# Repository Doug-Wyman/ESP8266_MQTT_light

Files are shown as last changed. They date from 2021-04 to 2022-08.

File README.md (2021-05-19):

# ESP8266_MQTT_light
Micropython code for controlling an RGB and White light 
using an ESP8266 controller board of my design

This code is poorly written alpha code to control a 12 VDC RGB light 
and a 12 VDC white light using MQTT. It works but needs improvement. 

The switches control on/off with a short press and dimming/brightening 
when they are held down.  

OSH Park is making my controller board (click on image)
<a href="https://oshpark.com/shared_projects/GQtievsf">
OSH Park</a>.  
The design is an Eagle cad design but there is a caveat!!
The switches come with 4 pins two pair of bussed through hole.
However even though the foot print is identical there are 
two varieties.  With the opposite connections. The board traces
will show the bussed pairs.

Being very new to ESP8266 and micropython it seems as though the code 
is near the memory limit of the ESP8266.
So I have eliminated all comments and extras.  
I welcome suggestions and corrections.  

The entire project is for a Home-Assistant installation.
I have 4 sets of lights working. I was experiencing disconnect fails 
when either the HASS server or the Mosquitto server was rebooted 
so I wrote the code so it reboots the ESP8266
GPIO-16 controlls the blue LED on the ESP8266 board I am using so the
code turns it on during boot then off once booted.  So it acts as an
indicator of when the board is in boot mode.

I have included a sample configuration for Home Assistant control of the module.
The script will return the version which will fill the sensor value.

The Code:
boot.py starts by loading the webrepl which probably won't be needed in production.
The parameters file is loaded and contains data for the WiFi connection, 
the MQTT instance, the pin data for the ESP8266 and such.

The status file is essentially the JSON state last saved so the light on boot 
is set to the last known state. 

Boot then calls main.  Main starts by opening the MQTT connection.
If there is an error in connecting, the program flashes the LED on the ESP8266 three times 
in a one second on one second off and exits.

On a good MQTT connection , the routine sets a callback address for received messages 
and returns the connected client.

The code enters the main loop. It does an MQTT message check first then 
the state of the switches is checked.  A short press/release will toggle the on/off state.
After the button is held down for a period longer than the counter is set for,
the light goes into a brighten/dim cycle.

After any change in state, the state file is updated and an MQTT status message is sent.
The last thing in the loop is a check to see when we sent the last status and
to send an update when timed out.

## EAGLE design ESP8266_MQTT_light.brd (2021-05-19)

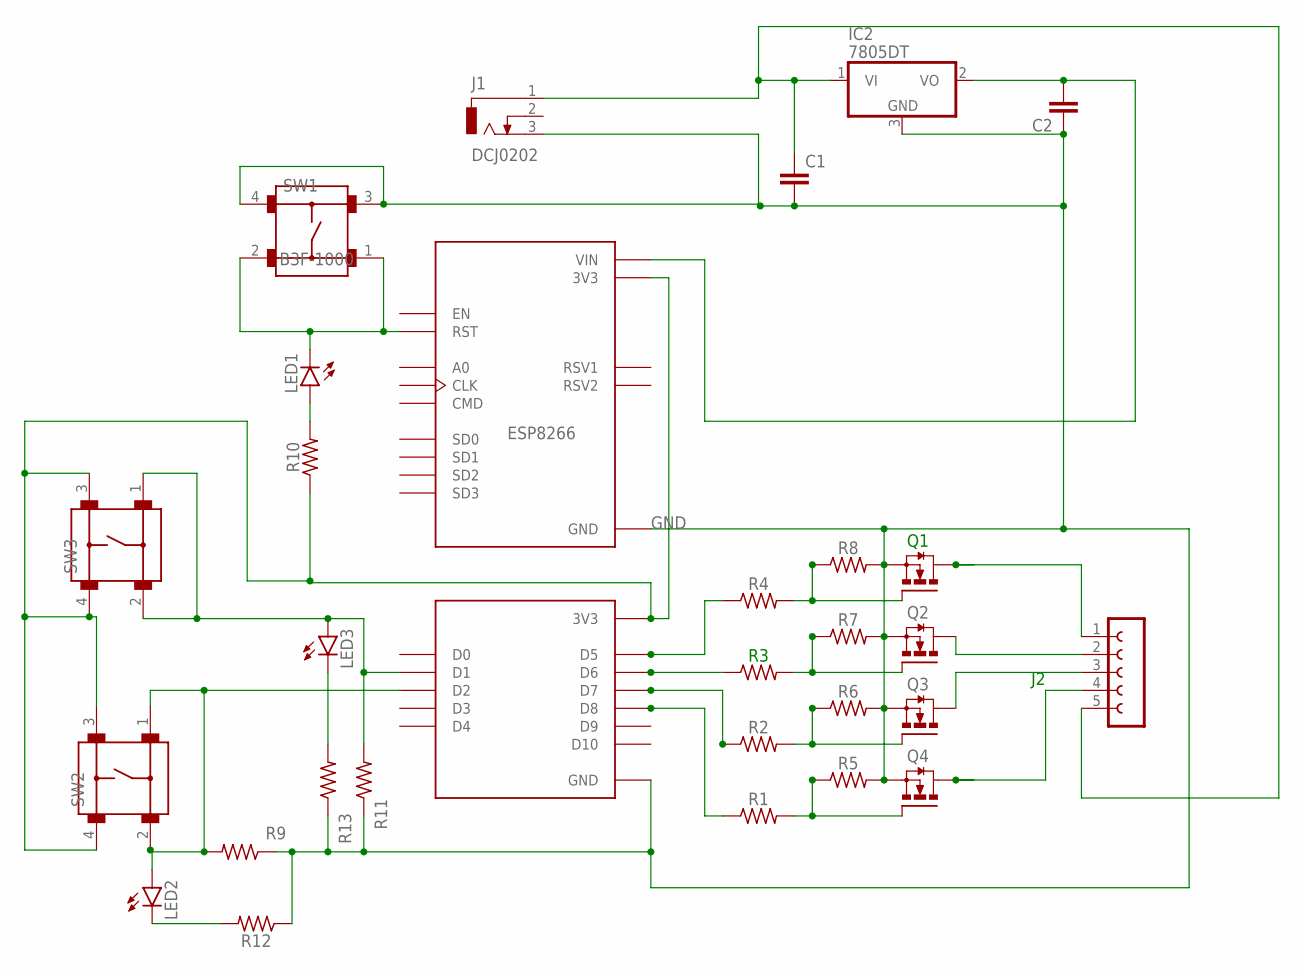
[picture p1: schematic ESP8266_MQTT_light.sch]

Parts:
C1, C2: CC1005; C1005
ESP8266: 113990105; SEEED_113990105
IC2: 7805DT; TO252
J1: DCJ0202
J2: RGBW1; FE05W
LED1, LED2, LED3: LEDCHIPLED_1206; CHIPLED_1206
Q1, Q2, Q3, Q4: IRF3704S; D2PACK
R1, R2, R3, R4: 1k; R1206
R5, R6, R7, R8, R9, R11: 10k; R1206
R10, R12, R13: 33; R1206
SW1, SW2, SW3: B3F-1000

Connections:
3.3VDC: ESP8266.J1_11 (3V3), ESP8266.J2_6 (3V3), ESP8266.J2_15 (3V3), R10.1, SW2.3, SW2.4, SW3.3, SW3.4
5VDC: C2.2, ESP8266.J1_15 (VIN), IC2.2 (VO)
12VDC: C1.1, IC2.1 (VI), J1.1, J2.5
B-IN: Q2.1 (G), R3.2, R7.1
B-MAIN: ESP8266.J2_9 (D6), R3.1
B-OUT: J2.2, Q2.2 (D)
G-IN: Q3.1 (G), R2.2, R6.1
G-MAIN: ESP8266.J2_10 (D7), R2.1
G-OUT: J2.3, Q3.2 (D)
GND: C1.2, C2.1, ESP8266.J1_10 (GND), ESP8266.J1_14 (GND), ESP8266.J2_7 (GND), ESP8266.J2_14 (GND), IC2.3 (GND), J1.3, Q1.3 (S), Q2.3 (S), Q3.3 (S), Q4.3 (S), R5.2, R6.2, R7.2, R8.2, R9.1, R11.1, R12.1, R13.1, SW1.3, SW1.4
unnamed: LED1.A, R10.2
unnamed: LED2.C, R12.2
unnamed: LED3.C, R13.2
unnamed: ESP8266.J2_3 (D2), LED2.A, R9.2, SW2.1, SW2.2
R-IN: Q4.1 (G), R1.2, R5.1
R-MAIN: ESP8266.J2_11 (D8), R1.1
R-OUT: J2.4, Q4.2 (D)
RESET: ESP8266.J1_13 (RST), LED1.C, SW1.1, SW1.2
W-CTL: ESP8266.J2_2 (D1), LED3.A, R11.2, SW3.1, SW3.2
W-IN: Q1.1 (G), R4.2, R8.1
W-MAIN: ESP8266.J2_8 (D5), R4.1
W-OUT: J2.1, Q1.2 (D)

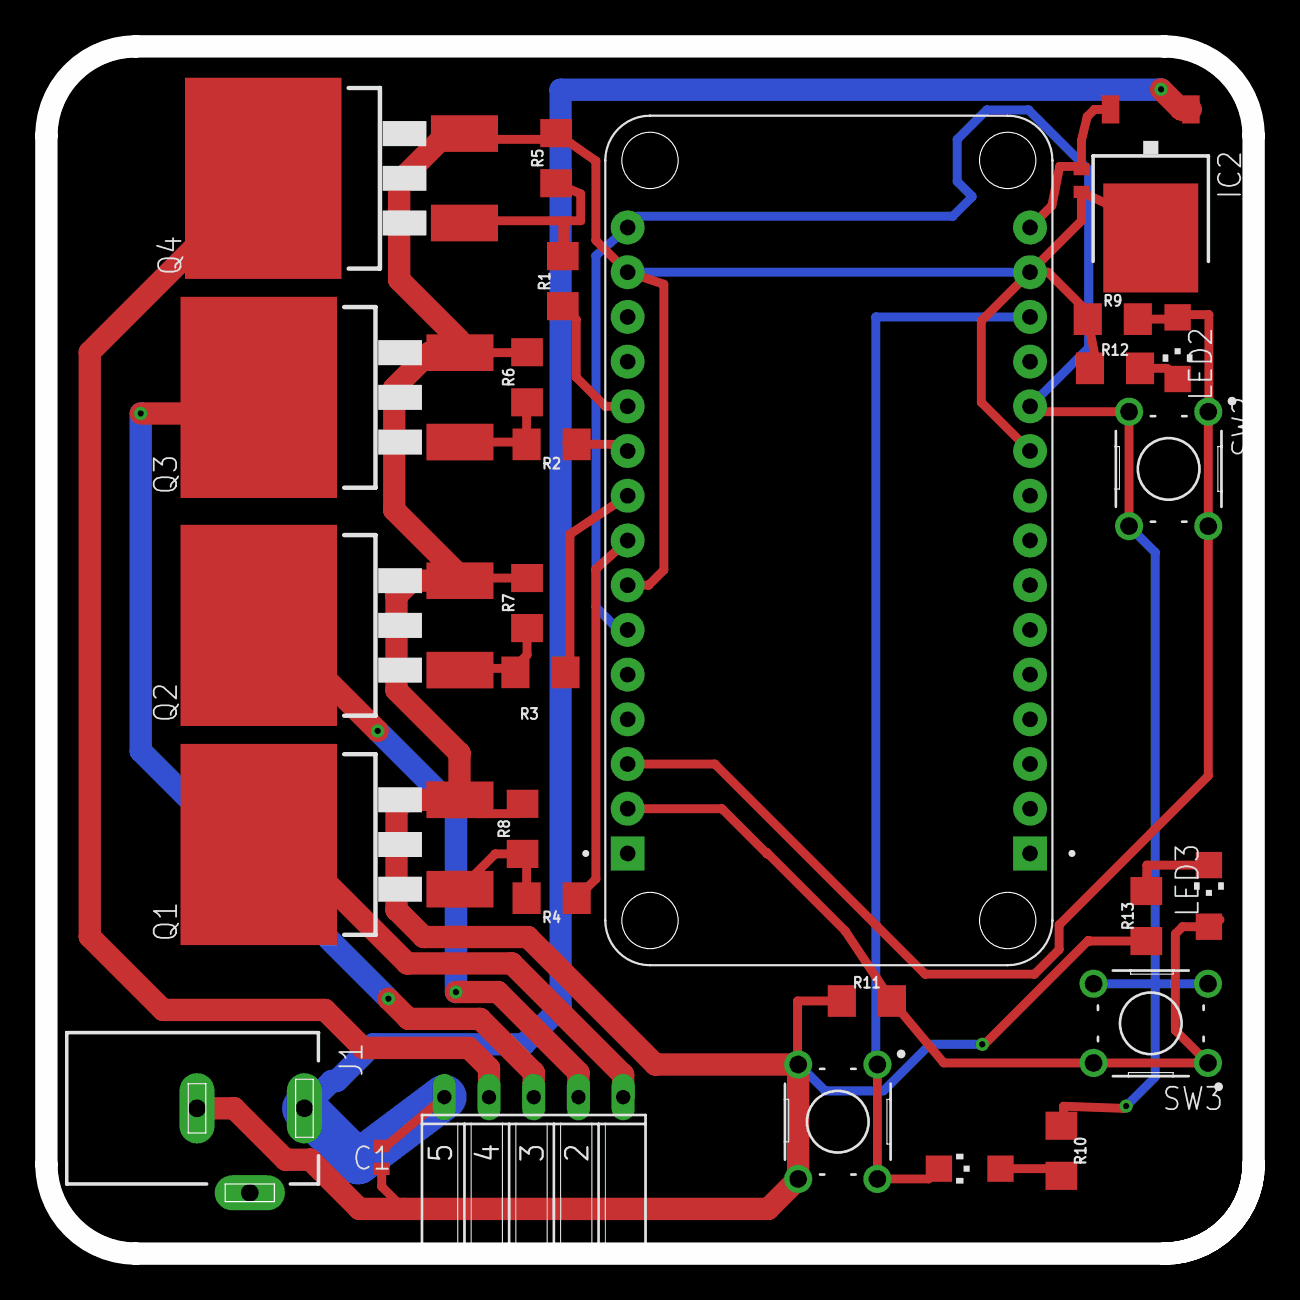
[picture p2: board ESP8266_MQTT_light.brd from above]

Board: 2 copper layers, 68.6 x 68.6 mm, 29 parts (0 on the bottom side), 22 nets.

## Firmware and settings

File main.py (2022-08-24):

#import machine
from machine import RTC
import time
from time import sleep
import os
import ujson
from umqtt.simple import MQTTClient
################# main for light ########################
def savestate():
  global status, BUSY
  statusfile = open('status', 'w')
  myjson = ujson.dumps(status)
  statusfile.write(str(myjson))
  statusfile.close()
  print("saved" + str(status))
  
def received(topic, inmsg):
  global status, BUSY, ROOT_TOPIC
  if not BUSY and topic != ROOT_TOPIC + b'white/state' and topic != ROOT_TOPIC + b'rgb/state':
    BUSY = True
    #print(topic, inmsg)
    msg = inmsg.decode('utf-8')
    print(msg)
    ##############WHITE######################
    if topic == ROOT_TOPIC + b'white/switch':
      print('ESP received switch')
      
      newset = ujson.loads(msg)
      print(newset)
      status['white']['state'] = newset.get('state', status['white']['state'])
      status['white']['brightness'] = newset.get('brightness', status['white']['brightness'])
      if status['white']['state'] == 'ON':
        WHITE_PIN.duty(status['white']['brightness'])
      else:
        WHITE_PIN.duty(0)
      client.publish(ROOT_TOPIC + b'white/state', str(ujson.dumps(status['white'])))
      savestate()
    ########################rgb#######################
    if topic == ROOT_TOPIC + b'version?':
      print('ESP version request')
      client.publish(ROOT_TOPIC + b'version', 'Version 2021.091')
    if topic == ROOT_TOPIC + b'rgb/switch':
      print('RGB received switch')
      newset = ujson.loads(msg)
      print(newset)
      status['rgb']['state'] = newset.get('state', status['rgb']['state'])
      status['rgb']['brightness'] = newset.get('brightness', status['rgb']['brightness'])
      status['rgb']['color'] = newset.get('color', status['rgb']['color'])
      if status['rgb']['state'] == 'ON':
        BRIGHTMULTIPLIER = float(status['rgb']['brightness'] / 1024)
        red = int(float(status['rgb']['color']['r'] /255) *1024)
        red = int(red * BRIGHTMULTIPLIER )
        green = int(float(status['rgb']['color']['g'] /255) * 1024)
        green = int(green * BRIGHTMULTIPLIER)
        blue = int(float(status['rgb']['color']['b'] /255) * 1025)
        blue = int(blue *  BRIGHTMULTIPLIER)
        print("red is:" + str(red))
        print("green is:" + str(green))
        print("blue is:" + str(blue))
        RED_PIN.duty(int(red))
        GREEN_PIN.duty(int(green))
        BLUE_PIN.duty(int(blue))
      else:
        RED_PIN.duty(0)
        GREEN_PIN.duty(0)
        BLUE_PIN.duty(0)
      client.publish(ROOT_TOPIC + b'rgb/state', str(ujson.dumps(status['rgb'])))
      savestate()
    BUSY = False
  else:
    print('.', end='')

def connect_and_subscribe():
  global CLIENT_ID, BROKER_ADDRESS, ROOT_TOPIC, client, SWITCH_PIN
  try:
    SWITCH_PIN.value(0)
    client = MQTTClient(CLIENT_ID, BROKER_ADDRESS)
    client.set_callback(received)
    client.connect()
    time.sleep(2)
    print("connecting")
    client.subscribe(ROOT_TOPIC + b'#')
    print('Connected to %s MQTT broker, subscribed to %s topic' % (BROKER_ADDRESS, ROOT_TOPIC))
    SWITCH_PIN.value(1)
    client.publish(ROOT_TOPIC + b'version', 'Version 2021.091')
    return client
  except:
    SWITCH_PIN.value(1)
    time.sleep(1)
    SWITCH_PIN.value(0)
    time.sleep(1)
    SWITCH_PIN.value(1)
    time.sleep(1)
    SWITCH_PIN.value(0)
    time.sleep(1)
    SWITCH_PIN.value(1)
    time.sleep(1)
    SWITCH_PIN.value(0)
    return None

################# main for light ########################
print("Loading.............")
client = connect_and_subscribe()
sleep(2)
last_message = 0
message_interval = 30
time_interval = 3600
#wdt.feed()
lastin = 1
counting = False
sw1count = 0
savtime = ''
#wdt.feed()
#print(dir(client.ping))
short_time = 5
down_time = 50

ctrlw_down = 0
ctrlw_raise = False
ctrlw_short = 0
ctrlw_level = 0

ctrlm_down = 0
ctrlm_raise = False
ctrlm_short = 0
ctrlm_level = 0
while 1:
  try:
    try:
        client.check_msg()
    except:
        print("error checking")
        client = connect_and_subscribe()
#######################start white contro
    if CTRL_WHITE.value() == 0:
      #print(".", end='')
      if ctrlw_short > 0:
        print("XX", end='')
        ctrlw_short += 1
        if ctrlw_short > short_time:
          ctrlw_short = 0
          print(str(status['white']['state']) == 'OFF')
          #######Toggle state##########
          if str(status['white']['state']) == 'OFF':
              WHITE_PIN.duty(status['white']['brightness'])
              status['white']['state'] = 'ON'
          else:
              WHITE_PIN.duty(0)
              status['white']['state'] = 'OFF'            
          client.publish(ROOT_TOPIC + b'white/state', str(ujson.dumps(status['white'])))
          savestate()
    if CTRL_WHITE.value() == 1:
      print("after short2" + str(ctrlw_short))
      print("||||||", end='')
      ctrlw_down = 0
      ctrlw_level = int(status['white']['brightness'])
      if ctrlw_short > 1:
        ctrlw_raise = True
      else:
        ctrlw_dimming = True
      print(ctrlw_level)
      while CTRL_WHITE.value() == 1:
        ctrlw_down += 1
        if ctrlw_down > down_time:
          WHITE_PIN.duty(ctrlw_level)
          if ctrlw_level < 1:
            ctrlw_raise = True
          if ctrlw_raise == True:
            ctrlw_level = int(ctrlw_level) + 1
            if int(ctrlw_level) > 1024:
              print("Stop Bright")
              #ctrlw_dimming = True
              ctrlw_raise = False
              ctrlw_short = 0
            else:
              ctrlw_raise = True
          else:
            ctrlw_level -= 1
            if ctrlw_level < 1:
              ctrlw_raise = True
        sleep(.01)
      if ctrlw_down > down_time:
        ctrlw_short = 0
        ctrlw_down = 0
      else:
        ctrlw_short = 1
      ctrlw_raise = False
      ctrlw_dimming = False
      status['white']['brightness'] = ctrlw_level
      if ctrlw_down == 0: 
        client.publish(ROOT_TOPIC + b'white/state', str(ujson.dumps(status['white'])))
        savestate()
      ctrlw_raise = False
      ctrlw_dimming = False
      print("after short1" + str(ctrlw_short))
#######################logic#################################
    if CTRL_MOOD.value() == 0:
      #print(".", end='')
      if ctrlm_short > 0:
        print("XX", end='')
        ctrlm_short += 1
        if ctrlm_short > short_time:
          ctrlm_short = 0
          print(str(status['rgb']['state']) == 'OFF')
          #######Toggle state##########
          if str(status['rgb']['state']) == 'OFF':
            #WHITE_PIN.duty(status['rgb']['brightness'])
            status['rgb']['state'] = 'ON'
            BRIGHTMULTIPLIER = float(status['rgb']['brightness'] / 1024)
            red = int(float(status['rgb']['color']['r'] /255) *1024)
            red = int(red * BRIGHTMULTIPLIER )
            green = int(float(status['rgb']['color']['g'] /255) * 1024)
            green = int(green * BRIGHTMULTIPLIER)
            blue = int(float(status['rgb']['color']['b'] /255) * 1025)
            blue = int(blue *  BRIGHTMULTIPLIER)
            print("red is:" + str(red))
            print("green is:" + str(green))
            print("blue is:" + str(blue))
            RED_PIN.duty(int(red))
            GREEN_PIN.duty(int(green))
            BLUE_PIN.duty(int(blue))
          else:
            RED_PIN.duty(0)
            GREEN_PIN.duty(0)
            BLUE_PIN.duty(0)
            status['rgb']['state'] = 'OFF'
          client.publish(ROOT_TOPIC + b'rgb/state', str(ujson.dumps(status['rgb'])))
          savestate()
    if CTRL_MOOD.value() == 1:
      print("||||||", end='')
      ctrlm_down = 0
      ctrlm_level = int(status['rgb']['brightness'])
      if ctrlm_short < 1:
        ctrlm_raise = True
      else:
        ctrlm_raise = False
      while CTRL_MOOD.value() == 1:
        ctrlm_down += 1
        if ctrlm_down > down_time:
          status['rgb']['brightness'] = ctrlm_level
          BRIGHTMULTIPLIER = float(status['rgb']['brightness'] / 1024)
          red = int(float(status['rgb']['color']['r'] /255) *1024)
          red = int(red * BRIGHTMULTIPLIER )
          green = int(float(status['rgb']['color']['g'] /255) * 1024)
          green = int(green * BRIGHTMULTIPLIER)
          blue = int(float(status['rgb']['color']['b'] /255) * 1025)
          blue = int(blue *  BRIGHTMULTIPLIER)
          print("red is:" + str(red))
          print("green is:" + str(green))
          print("blue is:" + str(blue))
          RED_PIN.duty(int(red))
          GREEN_PIN.duty(int(green))
          BLUE_PIN.duty(int(blue))
          if ctrlm_level < 1:
            ctrlm_raise = True
          if ctrlm_raise == True:
            ctrlm_level += 1
            if int(ctrlm_level) > 1024:
              ctrlm_raise = False
            else:
              ctrlm_raise = True
          else:
            ctrlm_level -= 1
            if ctrlm_level < 1:
              ctrlm_raise = True
          print(str(ctrlm_level) + "--" + str(int(red)))
        sleep(.01)
      if ctrlm_down > down_time:
        ctrlm_short = 0
        ctrlm_down = 0
      else:
        ctrlm_short = 1
      ctrlm_raise = False
      status['rgb']['brightness'] = ctrlm_level
      if ctrlm_down == 0: 
        client.publish(ROOT_TOPIC + b'rgb/state', str(ujson.dumps(status['rgb'])))
        savestate()
      ctrlm_raise = False
      ctrlm_dimming = False
############################################mood######################################
    if (time.time() - last_message) > float(message_interval):
        try:
            client.publish(ROOT_TOPIC + b'white/state', str(ujson.dumps(status['white'])))
            client.publish(ROOT_TOPIC + b'rgb/state', str(ujson.dumps(status['rgb'])))
            last_message = time.time()
        except:
            print("error sending")
            client = connect_and_subscribe()    
    elif time.time() < last_message:
        last_message = time.time()
    sleep(.1)
  except KeyboardInterrupt:
    print('Interrupted')
    os._exit(0)
  except:
    machine.reset()
################# main for light ########################

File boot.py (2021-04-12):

### boot for light ###
import gc
import machine
from machine import Pin, PWM
import network
import esp
import ujson
import webrepl

webrepl.start()
esp.osdebug(None)

gc.collect()

paramsfile = open('params', 'r')
json_params = paramsfile.read()
set_params = ujson.loads(json_params)
### boot for light ###
HOSTNAME = set_params['hostname']
NETADDRESS = set_params['address']
SSID = set_params['ssid']
PASSWORD = set_params['password']
BROKER_ADDRESS = set_params['broker']
TMP_TOPIC = set_params['topic']
ROOT_TOPIC = TMP_TOPIC.encode()
#CLIENT_ID = set_params['clientid']
CLIENT_ID = hex(int.from_bytes(machine.unique_id(), 'big'))
SWITCH_PIN = machine.Pin(int(set_params['switch']), machine.Pin.OUT)
FREQUENCY = set_params['freq']
# PWM PINS = PWM(Pin(12, 13,14,15), FREQUENCY)
BUSY = False
WHITE_PIN = PWM(Pin(set_params['white']), FREQUENCY)
RED_PIN = PWM(Pin(set_params['red']), FREQUENCY)
GREEN_PIN = PWM(Pin(set_params['green']), FREQUENCY)
BLUE_PIN = PWM(Pin(set_params['blue']), FREQUENCY)
RED_PIN.duty(0)
GREEN_PIN.duty(0)
BLUE_PIN.duty(0)
WHITE_PIN.duty(0)
CTRL_WHITE = machine.Pin(set_params['ctrl_white'], machine.Pin.IN)
CTRL_MOOD = machine.Pin(set_params['ctrl_mood'], machine.Pin.IN)

NTP_DELTA = 3155698800
ntphost = "pool.ntp.org"

paramsfile.close()
print("read" + str(set_params))
### boot for light ###

try:
  statusfile = open('status')
  myread = statusfile.read()
  status = ujson.loads(myread)

except OSError as exc:
  print('-----------')
  print(str(exc))
  print("can't load status")
  status = {
      'rgb': {
          "brightness": 512,
          "brightness_scale": 1024,
          "color": {
              "r": 1024,
              "g": 0,
              "b": 200,
              },
          "state": "ON",
          "transition": 2,
          },
      'white':{
          "brightness": 512,
          "brightness_scale": 1024,
          "state": "ON",
          "transition": 2,
          }
      }
SWITCH_PIN.value(0)
### boot for light ###
if status['rgb']['state'] == 'ON':
    BRIGHTMULTIPLIER = float(status['rgb']['brightness'] / 1024)
    red = (int(float(status['rgb']['color']['r']) * BRIGHTMULTIPLIER))
    green = (int(float(status['rgb']['color']['g']) * BRIGHTMULTIPLIER))
    blue = (int(float(status['rgb']['color']['b']) * BRIGHTMULTIPLIER))
    RED_PIN.duty(red)
    GREEN_PIN.duty(green)
    BLUE_PIN.duty(blue)
else:
    RED_PIN.duty(0)
    GREEN_PIN.duty(0)
    BLUE_PIN.duty(0)
if status['white']['state'] == 'ON':
    WHITE_PIN.duty(status['white']['brightness'])
else:
    WHITE_PIN.duty(0)
last_message = 0
message_interval = 5
time_interval = 600
counter = 0
### boot for light ###
STATION = network.WLAN(network.STA_IF)
STATION.active(True)
STATION.config(dhcp_hostname=HOSTNAME)
STATION.ifconfig(NETADDRESS)
STATION.connect(SSID, PASSWORD)

while STATION.isconnected() == False:
  pass

print('Connection successful')
print(STATION.ifconfig())
### boot for light ###

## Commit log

2021-04-20 Changed Switch on board
    The original board had an error on the switch
    [ESP8266_MQTT_light.brd, ESP8266_MQTT_light.sch]
2021-04-21 A revised board and caveat
2021-05-18 Changed Resistor footprint
    I changed the resistors to a 1206 SMD footprint
    [ESP8266_MQTT_light.brd, ESP8266_MQTT_light.sch]
2021-05-19 Board corrections
    Corrected amended board to allo for the larger 1206 resistors
    [ESP8266_MQTT_light.brd]
